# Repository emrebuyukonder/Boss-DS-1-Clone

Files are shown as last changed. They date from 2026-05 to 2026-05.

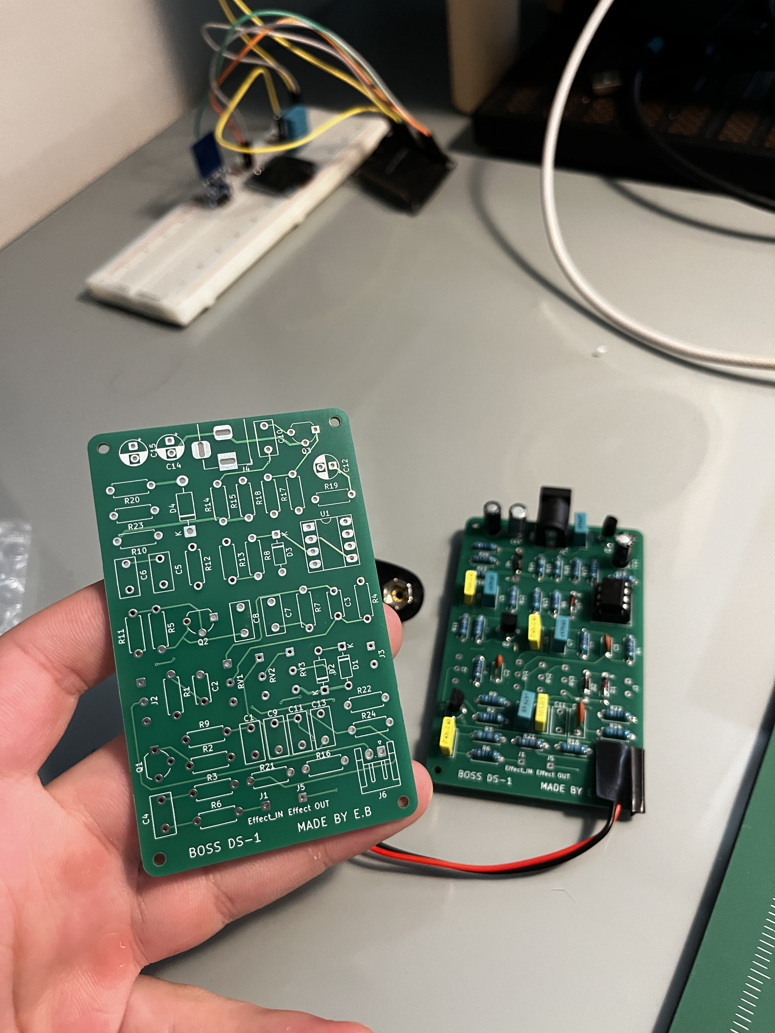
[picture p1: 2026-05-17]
media/IMG_4225.JPG

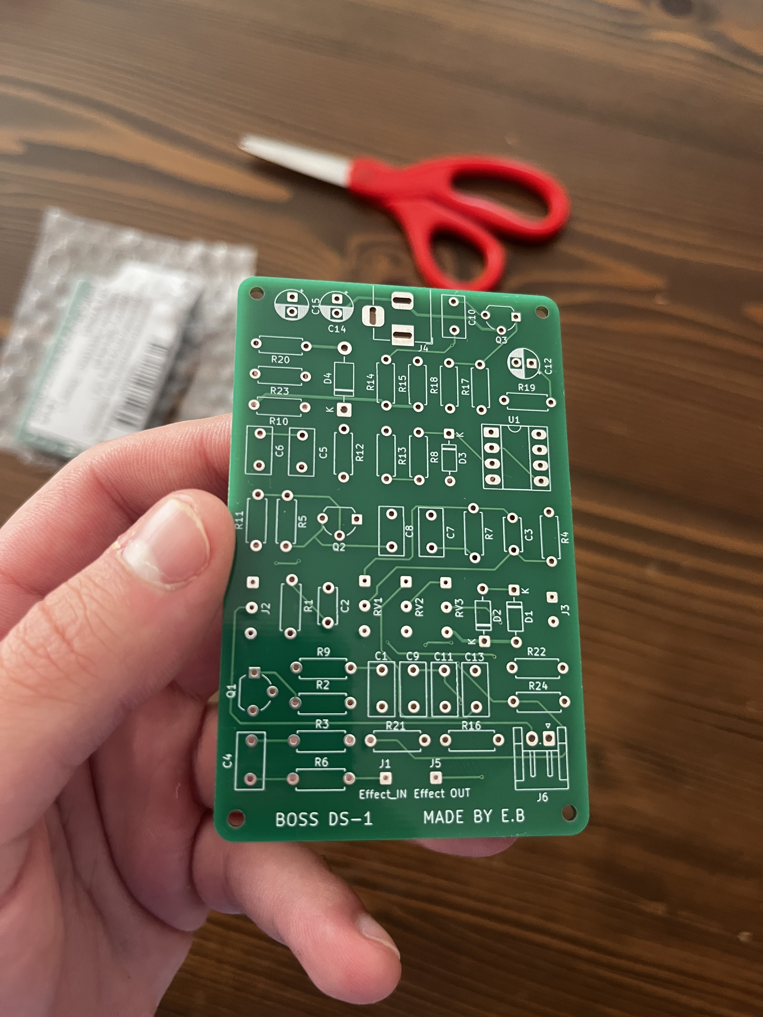
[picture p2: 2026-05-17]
media/IMG_4084.JPG

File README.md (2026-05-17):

# Boss DS-1 Distortion Clone (Custom Build)





## About The Project

This repository contains the schematic, PCB design files, and build documentation for a custom-built clone of the legendary Boss DS-1 Distortion pedal. Designed from the ground up using **KiCad**, this project aims to faithfully recreate the iconic hard-clipping distortion tone while implementing modern hardware practices such as True Bypass switching and optimized component routing.

## Key Features & Modifications

While the core audio path remains true to the original DS-1 architecture, several mechanical and component-level modifications were made based on the local availability of certain original components and hardware.

* **Custom Transistor Selection:** The original BC549C transistors were substituted with **JC2N3904S49 (NPN)** transistors for the input buffer (Q1), gain boost (Q2), and output buffer (Q3) stages. The PCB footprints were carefully matched to accommodate the E-B-C pinout of the 2N3904.
* **True Bypass Switching:** Unlike the original Boss buffered bypass, this build utilizes a **3PDT 9-Pin Latching Footswitch**. This ensures zero tone coloration when the pedal is disengaged and includes an independent pole for the status LED.
* **Smart Power Management:** Integrated a Stereo Input Jack to act as a ground-shunt switch. The 9V battery is completely disconnected from the circuit when the input cable is unplugged, preserving battery life.
* **Capacitor Accuracy:** High-quality film and ceramic capacitors are used throughout the tone stack and filtering stages (e.g., precise 100pF and 220pF ceramics for RF filtering in the op-amp feedback loop).

## Tools & Technologies Used

* **EDA Software:** KiCad (Schematic Capture & PCB Layout)
* **Testing & Measurement:** UNI-T UT33D+ Digital Multimeter
* **Audio Components:** 1/4" Mono/Stereo Jacks, Custom PCB.

## Hardware Wiring Guide

Proper off-board wiring is critical for a noise-free pedal. Here is the standard implementation used in this build:

* **Input Jack (Stereo):**
   * *Tip:* Routed to 3PDT Switch (Input).
    * *Ring:* Connected to the 9V Battery Negative (Black wire).
    * *Sleeve:* Connected to System Ground (Star Grounding).
* **Output Jack (Mono):**
    * *Tip:* Routed from 3PDT Switch (Output).
    * *Sleeve:* Connected to System Ground.

## Author

Designed and built by **Erdoğan Emre Büyükönder** (Music Producer / Composer under the pseudonym *Magnus Dux*). 

As an Electrical-Electronics Engineering student and a music producer, this project bridges the gap between theoretical circuit analysis and practical, stage-ready audio equipment.

---
*Note: The "Boss" and "DS-1" names are trademarks of Roland Corporation. This project is strictly for educational purposes and personal use.*

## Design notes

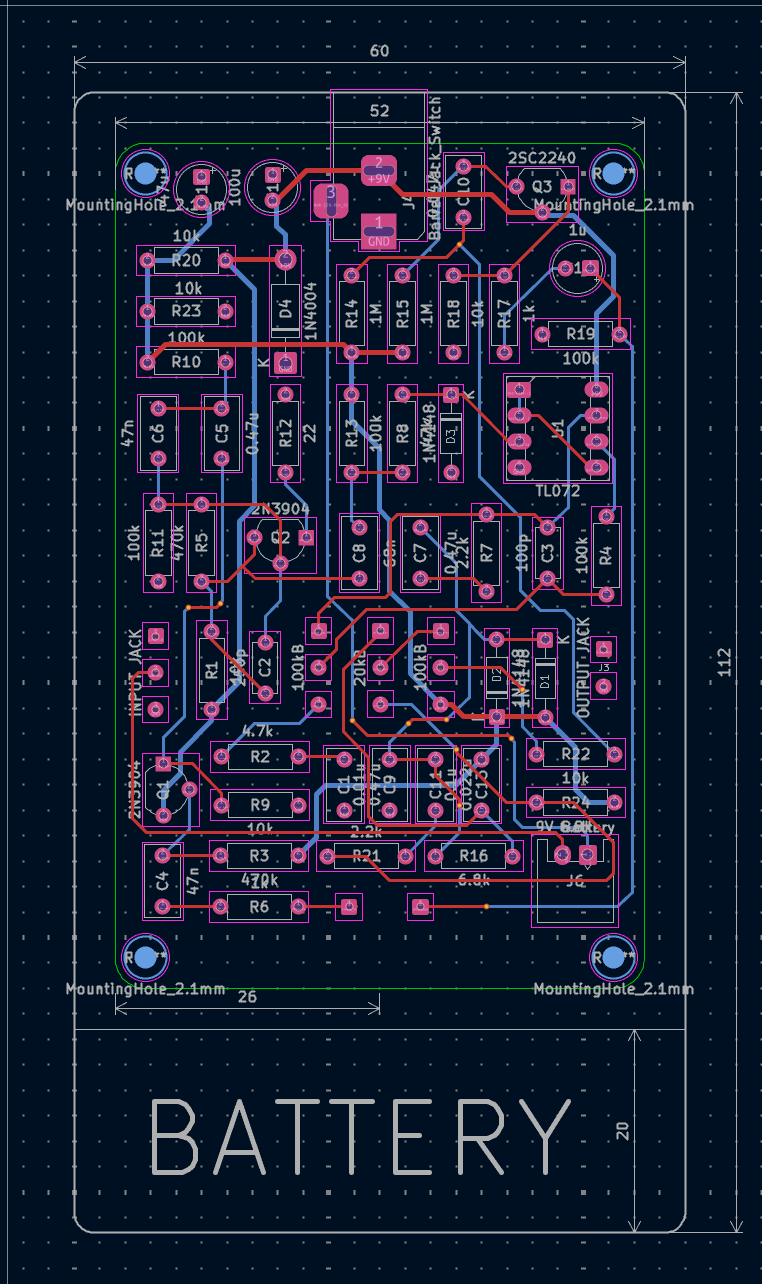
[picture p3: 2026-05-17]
hardware/Boss DS-1 - PCB Layout.png

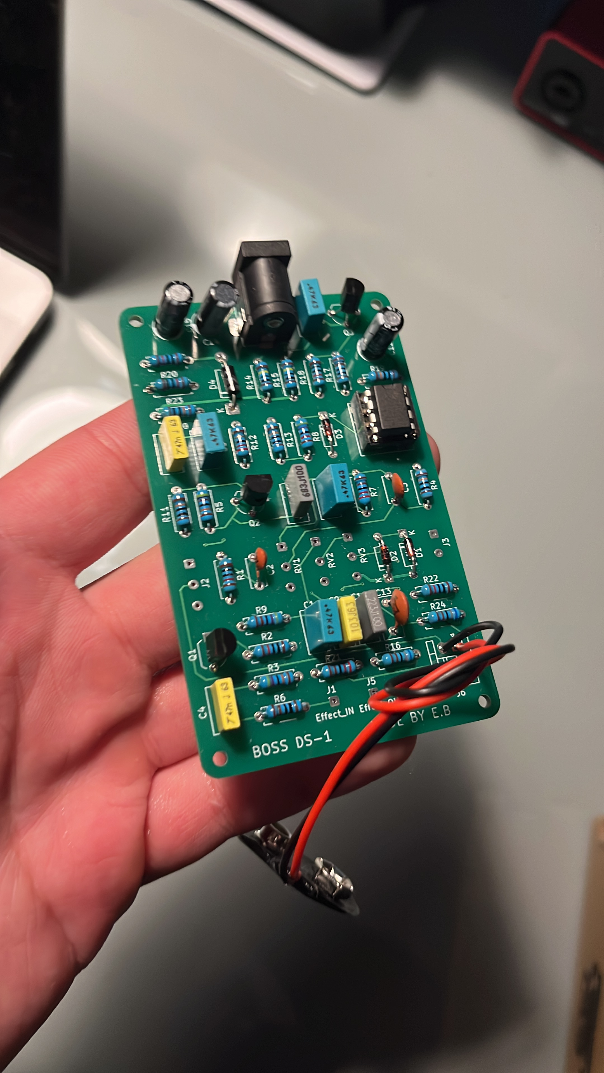
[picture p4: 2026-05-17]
media/FDCBED5D-9F43-463E-B93E-2196EB60EEDA.jpg

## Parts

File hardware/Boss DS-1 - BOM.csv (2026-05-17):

Reference | Qty | Value | DNP | Exclude from BOM | Exclude from Board | Footprint | Datasheet
U1 | 1 | TL072 |  |  |  | Package_DIP:DIP-8_W7.62mm_Socket_LongPads | http://www.ti.com/lit/ds/symlink/tl071.pdf
SW1 | 1 | SW_Slide_DPDT |  |  |  |  | ~
RV2 | 1 | 20kB |  |  |  | Connector_Wire:SolderWire-0.1sqmm_1x03_P3.6mm_D0.4mm_OD1mm | ~
RV1,RV3 | 2 | 100kB |  |  |  | Connector_Wire:SolderWire-0.1sqmm_1x03_P3.6mm_D0.4mm_OD1mm | ~
R16,R24 | 2 | 6.8k |  |  |  | Resistor_THT:R_Axial_DIN0207_L6.3mm_D2.5mm_P7.62mm_Horizontal | ~
R14,R15 | 2 | 1M |  |  |  | Resistor_THT:R_Axial_DIN0207_L6.3mm_D2.5mm_P7.62mm_Horizontal | ~
R12 | 1 | 22 |  |  |  | Resistor_THT:R_Axial_DIN0207_L6.3mm_D2.5mm_P7.62mm_Horizontal | ~
R8 | 1 | 47k |  |  |  | Resistor_THT:R_Axial_DIN0207_L6.3mm_D2.5mm_P7.62mm_Horizontal | ~
R7,R21 | 2 | 2.2k |  |  |  | Resistor_THT:R_Axial_DIN0207_L6.3mm_D2.5mm_P7.62mm_Horizontal | ~
R6,R17 | 2 | 1k |  |  |  | Resistor_THT:R_Axial_DIN0207_L6.3mm_D2.5mm_P7.62mm_Horizontal | ~
R4,R10,R11,R13,R19 | 5 | 100k |  |  |  | Resistor_THT:R_Axial_DIN0207_L6.3mm_D2.5mm_P7.62mm_Horizontal | ~
R3,R5 | 2 | 470k |  |  |  | Resistor_THT:R_Axial_DIN0207_L6.3mm_D2.5mm_P7.62mm_Horizontal | ~
R2 | 1 | 4.7k |  |  |  | Resistor_THT:R_Axial_DIN0207_L6.3mm_D2.5mm_P7.62mm_Horizontal | ~
R1,R9,R18,R20,R22,R23 | 6 | 10k |  |  |  | Resistor_THT:R_Axial_DIN0207_L6.3mm_D2.5mm_P7.62mm_Horizontal | ~
Q1,Q2,Q3 | 3 | 2N3904 |  |  |  | Package_TO_SOT_THT:TO-92_Wide | https://media.digikey.com/pdf/Data%20Sheets/Toshiba%20PDFs/2SC1815.pdf
J6 | 1 | 9V Battery |  |  |  | Connector_JST:JST_EH_S2B-EH_1x02_P2.50mm_Horizontal | ~
J5 | 1 | Effect OUT |  |  |  | Connector_Wire:SolderWire-0.1sqmm_1x01_D0.4mm_OD1mm | ~
J4 | 1 | Barrel_Jack_Switch |  |  |  | Connector_BarrelJack:BarrelJack_Horizontal | ~
J3 | 1 | OUTPUT JACK |  |  |  | Connector_Wire:SolderWire-0.1sqmm_1x02_P3.6mm_D0.4mm_OD1mm | ~
J2 | 1 | INPUT JACK |  |  |  | Connector_Wire:SolderWire-0.1sqmm_1x03_P3.6mm_D0.4mm_OD1mm | ~
J1 | 1 | Effect_IN |  |  |  | Connector_Wire:SolderWire-0.1sqmm_1x01_D0.4mm_OD1mm | ~
D4 | 1 | 1N4004 |  |  |  | Diode_THT:D_DO-41_SOD81_P10.16mm_Horizontal | ~
D1,D2,D3 | 3 | 1N4148 |  |  |  | Diode_THT:D_DO-35_SOD27_P7.62mm_Horizontal | ~
C15 | 1 | 47u |  |  |  | Capacitor_THT:CP_Radial_D5.0mm_P2.50mm | ~
C14 | 1 | 100u |  |  |  | Capacitor_THT:CP_Radial_D5.0mm_P2.50mm | ~
C13 | 1 | 0.1u |  |  |  | Capacitor_THT:C_Rect_L7.2mm_W3.5mm_P5.00mm_FKS2_FKP2_MKS2_MKP2 | ~
C12 | 1 | 1u |  |  |  | Capacitor_THT:CP_Radial_D5.0mm_P2.50mm | ~
C11 | 1 | 0.022u |  |  |  | Capacitor_THT:C_Rect_L7.2mm_W3.5mm_P5.00mm_FKS2_FKP2_MKS2_MKP2 | ~
C10 | 1 | 0.047u |  |  |  | Capacitor_THT:C_Rect_L7.2mm_W3.5mm_P5.00mm_FKS2_FKP2_MKS2_MKP2 | ~
C9 | 1 | 0.01u |  |  |  | Capacitor_THT:C_Rect_L7.2mm_W3.5mm_P5.00mm_FKS2_FKP2_MKS2_MKP2 | ~
C8 | 1 | 68n |  |  |  | Capacitor_THT:C_Rect_L7.2mm_W3.5mm_P5.00mm_FKS2_FKP2_MKS2_MKP2 | ~
C4,C6 | 2 | 47n |  |  |  | Capacitor_THT:C_Rect_L7.2mm_W3.5mm_P5.00mm_FKS2_FKP2_MKS2_MKP2 | ~
C3 | 1 | 100p |  |  |  | Capacitor_THT:C_Disc_D5.0mm_W2.5mm_P5.00mm | ~
C2 | 1 | 250p |  |  |  | Capacitor_THT:C_Disc_D5.0mm_W2.5mm_P5.00mm | ~
C1,C5,C7 | 3 | 0.47u |  |  |  | Capacitor_THT:C_Rect_L7.2mm_W3.5mm_P5.00mm_FKS2_FKP2_MKS2_MKP2 | ~

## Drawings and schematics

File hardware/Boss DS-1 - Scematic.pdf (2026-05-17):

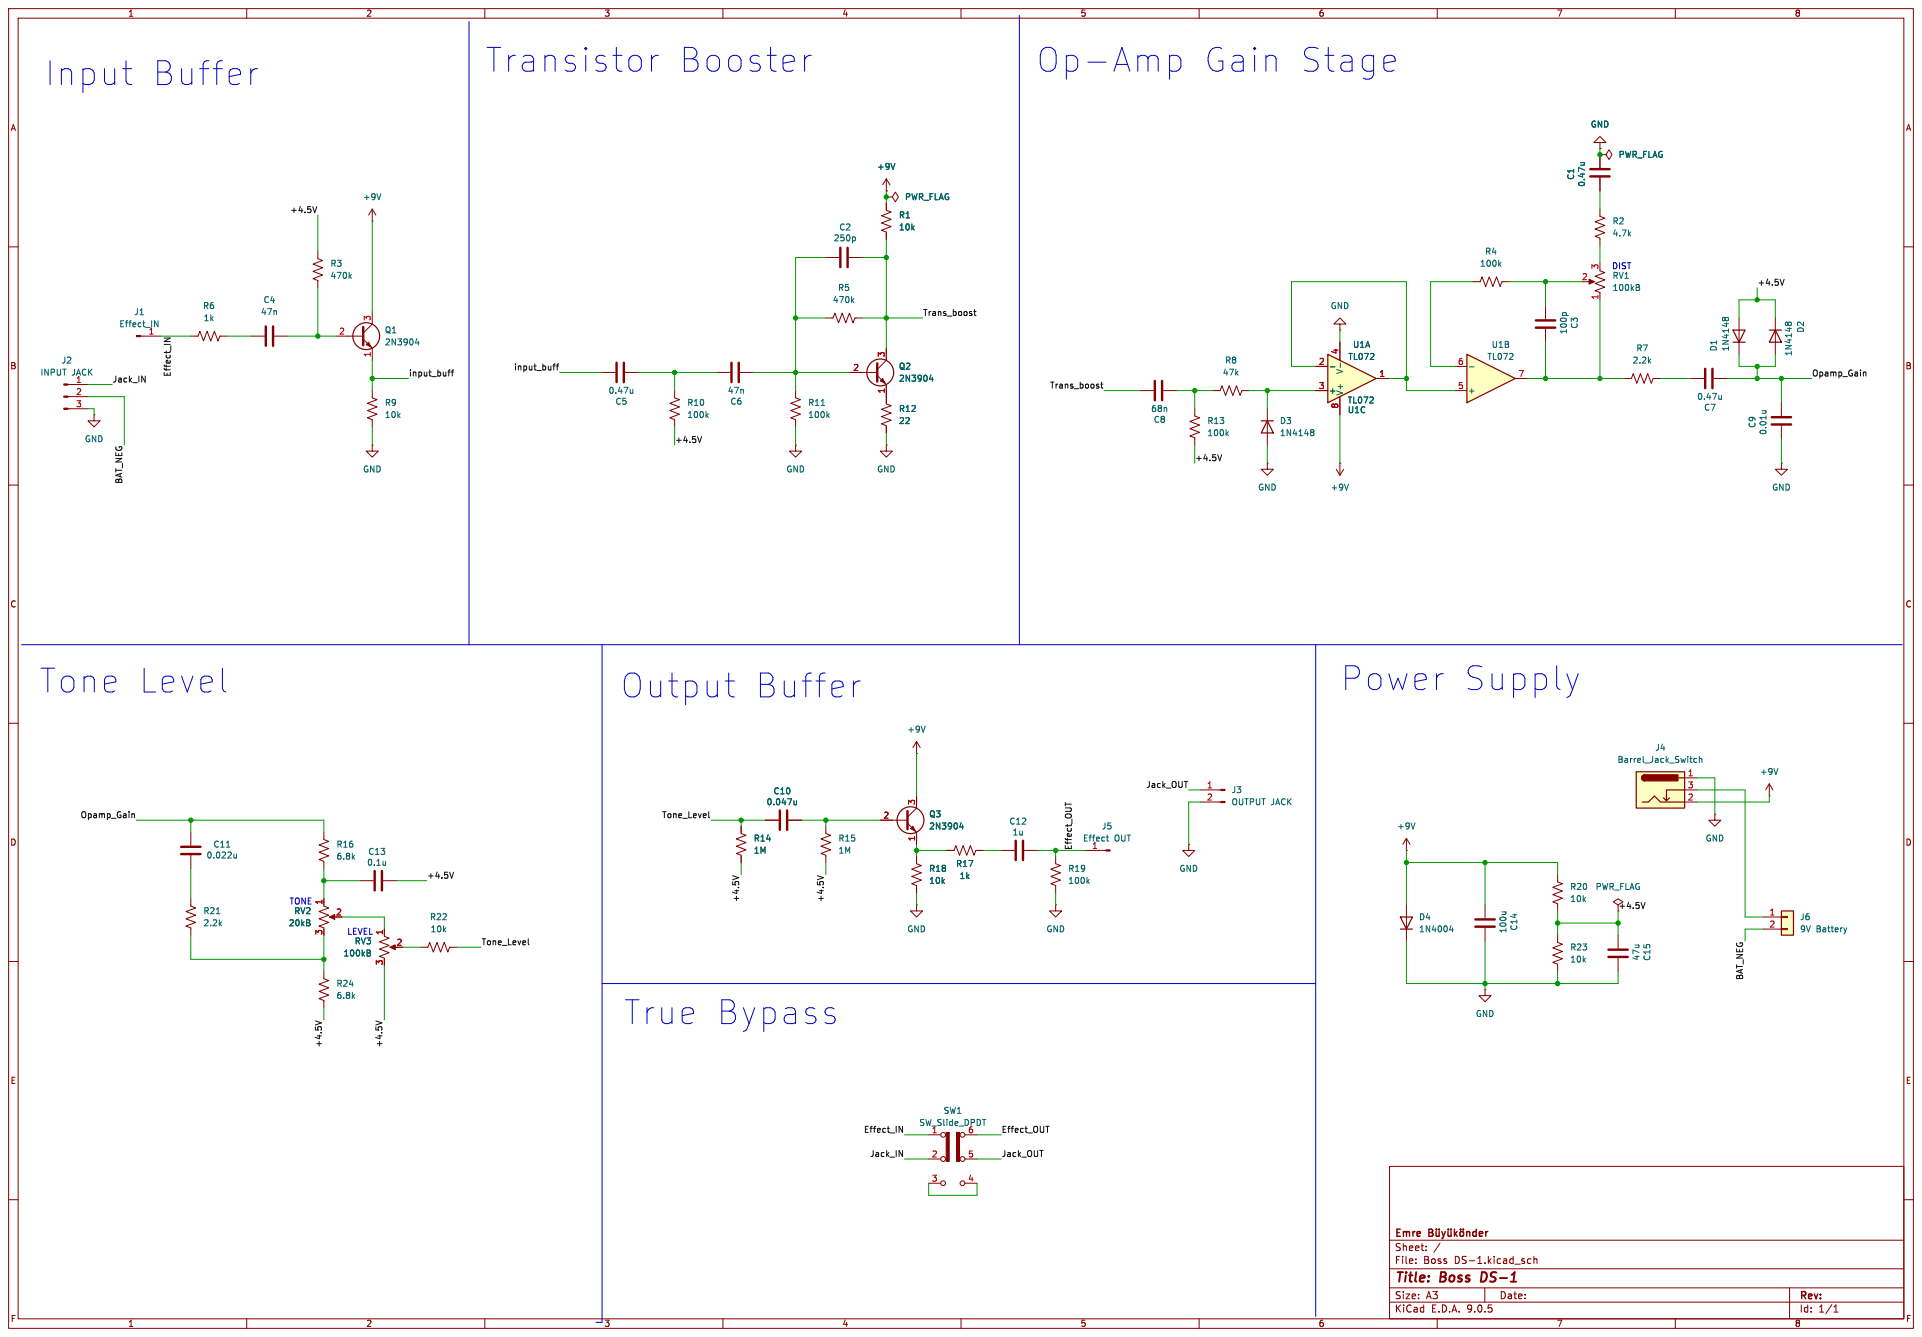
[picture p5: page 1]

Op-Amp Gain Stage

Id: 1/1 Title: Boss DS-1

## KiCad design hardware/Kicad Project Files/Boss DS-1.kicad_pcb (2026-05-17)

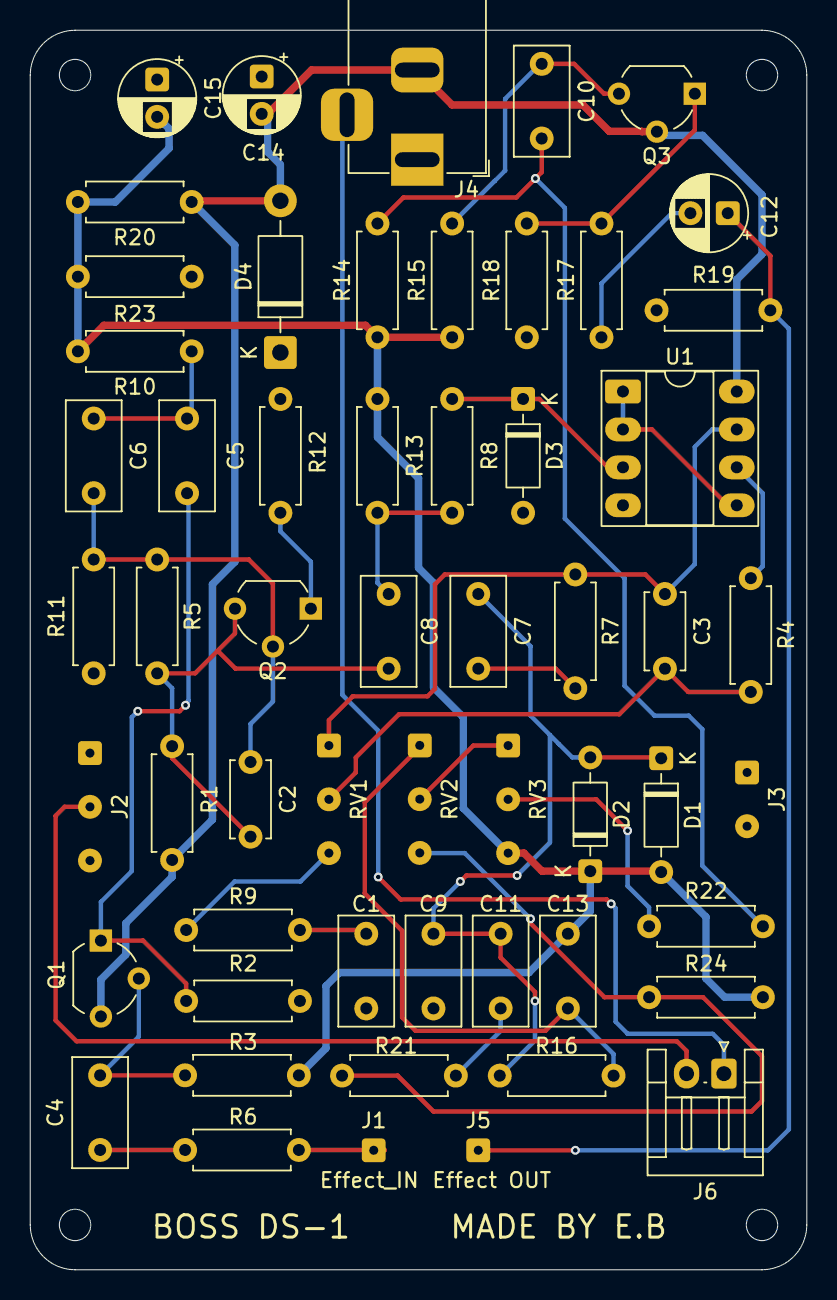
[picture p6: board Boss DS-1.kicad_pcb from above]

Board: 2 copper layers, 52.0 x 83.0 mm, 56 parts (0 on the bottom side), 33 nets.

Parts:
C1, C5, C7: 0.47u; C_Rect_L7.2mm_W3.5mm_P5.00mm_FKS2_FKP2_MKS2_MKP2
C2: 250p; C_Disc_D5.0mm_W2.5mm_P5.00mm
C3: 100p; C_Disc_D5.0mm_W2.5mm_P5.00mm
C4, C6: 47n; C_Rect_L7.2mm_W3.5mm_P5.00mm_FKS2_FKP2_MKS2_MKP2
C8: 68n; C_Rect_L7.2mm_W3.5mm_P5.00mm_FKS2_FKP2_MKS2_MKP2
C9: 0.01u; C_Rect_L7.2mm_W3.5mm_P5.00mm_FKS2_FKP2_MKS2_MKP2
C10: 0.047u; C_Rect_L7.2mm_W3.5mm_P5.00mm_FKS2_FKP2_MKS2_MKP2
C11: 0.022u; C_Rect_L7.2mm_W3.5mm_P5.00mm_FKS2_FKP2_MKS2_MKP2
C12: 1u; CP_Radial_D5.0mm_P2.50mm
C13: 0.1u; C_Rect_L7.2mm_W3.5mm_P5.00mm_FKS2_FKP2_MKS2_MKP2
C14: 100u; CP_Radial_D5.0mm_P2.50mm
C15: 47u; CP_Radial_D5.0mm_P2.50mm
D1, D2, D3: 1N4148; D_DO-35_SOD27_P7.62mm_Horizontal
D4: 1N4004; D_DO-41_SOD81_P10.16mm_Horizontal
J1: Effect_IN; SolderWire-0.1sqmm_1x01_D0.4mm_OD1mm
J2: INPUT JACK; SolderWire-0.1sqmm_1x03_P3.6mm_D0.4mm_OD1mm
J3: OUTPUT JACK; SolderWire-0.1sqmm_1x02_P3.6mm_D0.4mm_OD1mm
J4: Barrel_Jack_Switch; BarrelJack_Horizontal
J5: Effect OUT; SolderWire-0.1sqmm_1x01_D0.4mm_OD1mm
J6: 9V Battery; JST_EH_S2B-EH_1x02_P2.50mm_Horizontal
Q1, Q2: 2N3904; TO-92_Wide
Q3: 2SC2240; TO-92_Wide
R1, R9, R18, R20, R22, R23: 10k; R_Axial_DIN0207_L6.3mm_D2.5mm_P7.62mm_Horizontal
R2: 4.7k; R_Axial_DIN0207_L6.3mm_D2.5mm_P7.62mm_Horizontal
R3, R5: 470k; R_Axial_DIN0207_L6.3mm_D2.5mm_P7.62mm_Horizontal
R4, R10, R11, R13, R19: 100k; R_Axial_DIN0207_L6.3mm_D2.5mm_P7.62mm_Horizontal
R6, R17: 1k; R_Axial_DIN0207_L6.3mm_D2.5mm_P7.62mm_Horizontal
R7, R21: 2.2k; R_Axial_DIN0207_L6.3mm_D2.5mm_P7.62mm_Horizontal
R8: 47k; R_Axial_DIN0207_L6.3mm_D2.5mm_P7.62mm_Horizontal
R12: 22; R_Axial_DIN0207_L6.3mm_D2.5mm_P7.62mm_Horizontal
R14, R15: 1M; R_Axial_DIN0207_L6.3mm_D2.5mm_P7.62mm_Horizontal
R16, R24: 6.8k; R_Axial_DIN0207_L6.3mm_D2.5mm_P7.62mm_Horizontal
RV1, RV3: 100kB; SolderWire-0.1sqmm_1x03_P3.6mm_D0.4mm_OD1mm
RV2: 20kB; SolderWire-0.1sqmm_1x03_P3.6mm_D0.4mm_OD1mm
U1: TL072; DIP-8_W7.62mm_Socket_LongPads

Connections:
+9V: C14.2, D4.2 (A), J4.2, Q1.3 (C), Q3.2 (C), R1.1, R20.1, U1.8 (V+)
/+4.5V: C13.1, C15.2, D1.2 (A), D2.1 (K), R3.2, R10.2, R13.2, R14.1, R15.1, R20.2, R23.1, R24.2, RV3.3
/BAT_NEG: J2.2, J6.2
/Effect_IN: J1.1, R6.1
/Effect_OUT: C12.1, J5.1, R19.2
/Opamp_Gain: C7.2, C9.1, C11.2, D1.1 (K), D2.2 (A), R16.1
/Tone_Level: C10.2, R14.2, R22.2
/Trans_boost: C2.2, C8.1, Q2.3 (C), R1.2, R5.2
/input_buff: C5.1, Q1.1 (E), R9.1
GND: C1.1, C9.2, C14.1, C15.1, D3.2 (A), D4.1 (K), J2.3, J3.2, J4.1, R9.2, R11.2, R12.2, R18.1, R19.1, R23.2, U1.4 (V-)
unnamed: C1.2, R2.2
unnamed: C3.1, R7.1, RV1.1, U1.7
unnamed: C3.2, R4.2, RV1.2
unnamed: C4.1, R6.2
unnamed: C5.2, C6.1, R10.1
unnamed: C7.1, R7.2
unnamed: C8.2, R8.1, R13.1
unnamed: C11.1, R21.1
unnamed: C12.2, R17.1
unnamed: C13.2, R16.2, RV2.1
unnamed: D3.1 (K), R8.2, U1.3 (+)
unnamed: J4.3, J6.1
unnamed: C4.2, Q1.2 (B), R3.1
unnamed: C2.1, C6.2, Q2.2 (B), R5.1, R11.1
unnamed: Q2.1 (E), R12.1
unnamed: C10.1, Q3.3 (B), R15.2
unnamed: Q3.1 (E), R17.2, R18.2
unnamed: R2.1, RV1.3
unnamed: R21.2, R24.1, RV2.3
unnamed: R22.1, RV3.2
unnamed: RV2.2, RV3.1
unnamed: U1.1, U1.2 (-), U1.5 (+)
unnamed: R4.1, U1.6 (-)

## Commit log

2026-05-17 All the files necessary to build this project has been added.
    [Boss DS-1-B_Cu.gbr, Boss DS-1-B_Mask.gbr, Boss DS-1-B_Silkscreen.gbr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]
2026-05-17 Update 2
    [Boss DS-1-B_Cu.gbr, Boss DS-1-B_Mask.gbr, Boss DS-1-B_Silkscreen.gbr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]
2026-05-17 Create Boss DS-1 - BOM.csv
    [Boss DS-1 - BOM.csv]
